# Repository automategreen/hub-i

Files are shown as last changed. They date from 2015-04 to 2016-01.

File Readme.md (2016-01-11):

Insteon Compatible WiFi Hub
===============
> Open Source Secure WiFi Hub for Insteon Devices
***

The Hub I is designed to provide secure cloud control to your existing Insteon network. We are currently working on prototyping with the Spark Core. The final solutions will use the Spark Photon P1.

## Feedback & Support

Please let us know if you like this concept.  We need your support and encouragement to make the prototype a product. Send us an email, [support@automategreen.com](mailto:support@automategreen.com), or a tweet, [@AutomateGreen](https://twitter.com/AutomateGreen).

## Work In Progress

Link Record DB - The all-link record database is not implement yet.  Linking will not work until this is complete.

## UPDATE - CRC Solved!!!

The Insteon CRC issue has been solved.  Thank you Wieslaw Strugala for your help.  Insteon uses two different CRC methods: one for power line (PL) and one for radio (RF).  Wieslaw has solved the PL CRC and pointed me to Peter Shipley who solved the Insteon RF CRC, <https://github.com/evilpete/insteonrf>.  Many thanks to Peter, Wieslaw, and all the others who helped.

## Insteon Over the Spark Cloud

To improve on the standard Insteon Hub, we've used the awesome [Spark OS](https://www.spark.io/) to extend the PLM interface security to the cloud.  No unencrypted open information here. All messaging pass securely to and from the Spark OS.

### Insteon Message

All Insteon messages are sent as HEX strings.  The HEX strings allow for all Insteon messages to fit within the Spark OS packet restriction.  It also minimizes the logic for the hub.

Because the HEX is cryptic and requires an in-depth knowledge of the Insteon HEX commands, we added support for the hub to our Node.js module, [home-controller](https://github.com/automategreen/home-controller).

### Sending an Insteon Command

All the Insteon commands can be sent using HEX strings.

For example, to turn an Insteon switch on, you send a direct command to turn on the device.

```
$ spark call 0123456789ABCDEFGHI insteon 0262AABBCC0F117F
8
```

- Direct command: 0262
- Device ID: AABBCC
- Flags: 0F
- Action (turn on): 11
- Level (50%): 7F

The light turns on to 50%, and the call returns the number of bytes sent to the PLM. In this case `8`. 

### Receiving an Insteon Event

Now you can control your device, but you want more.  You want notifications in real time of from you devices - no problem.  You can use the Spark OS subscribe to receive Insteon messages from your device.

Here's and example of getting notified of motion detected by a motion sensor.

```
$ spark subscribe insteon 0123456789ABCDEFGHI
Subscribing to "insteon" from 0123456789ABCDEFGHI's stream
Listening to: /v1/devices/0123456789ABCDEFGHI/events/insteon
{"name":"insteon","data":"0250aabbcc000001cf1101","ttl":"60","published_at":"2015-01-12T21:16:48.361Z","coreid":"0123456789ABCDEFGHI"}
```

The data field contains the Insteon message.

- Received command: 0250
- Device ID: AABBCC
- Group: 000001
- Flags: cf
- Action (motion detected): 11

### Insteon Request/Response

If you want to query a device for information, you combine the `call` and `subscribe` together. 

First, make sure you subscribe.

```
spark subscribe insteon 0123456789ABCDEFGHI
Subscribing to "insteon" from 0123456789ABCDEFGHI's stream
Listening to: /v1/devices/0123456789ABCDEFGHI/events/insteon
```

Then, send the request. For example, get the light level.

```
$ spark call 0123456789ABCDEFGHI insteon 0262aabbcc0f1900
2
```

You'll then receive the Insteon response from the subscription.

```
{"name":"insteon","data":"0250aabbccffffff2f01ff","ttl":"60","published_at":"2015-01-12T21:16:48.361Z","coreid":"0123456789ABCDEFGHI"}
```

Light is on at 100%.  

If your want an easier way, you can use [home-controller](https://github.com/automategreen/home-controller).

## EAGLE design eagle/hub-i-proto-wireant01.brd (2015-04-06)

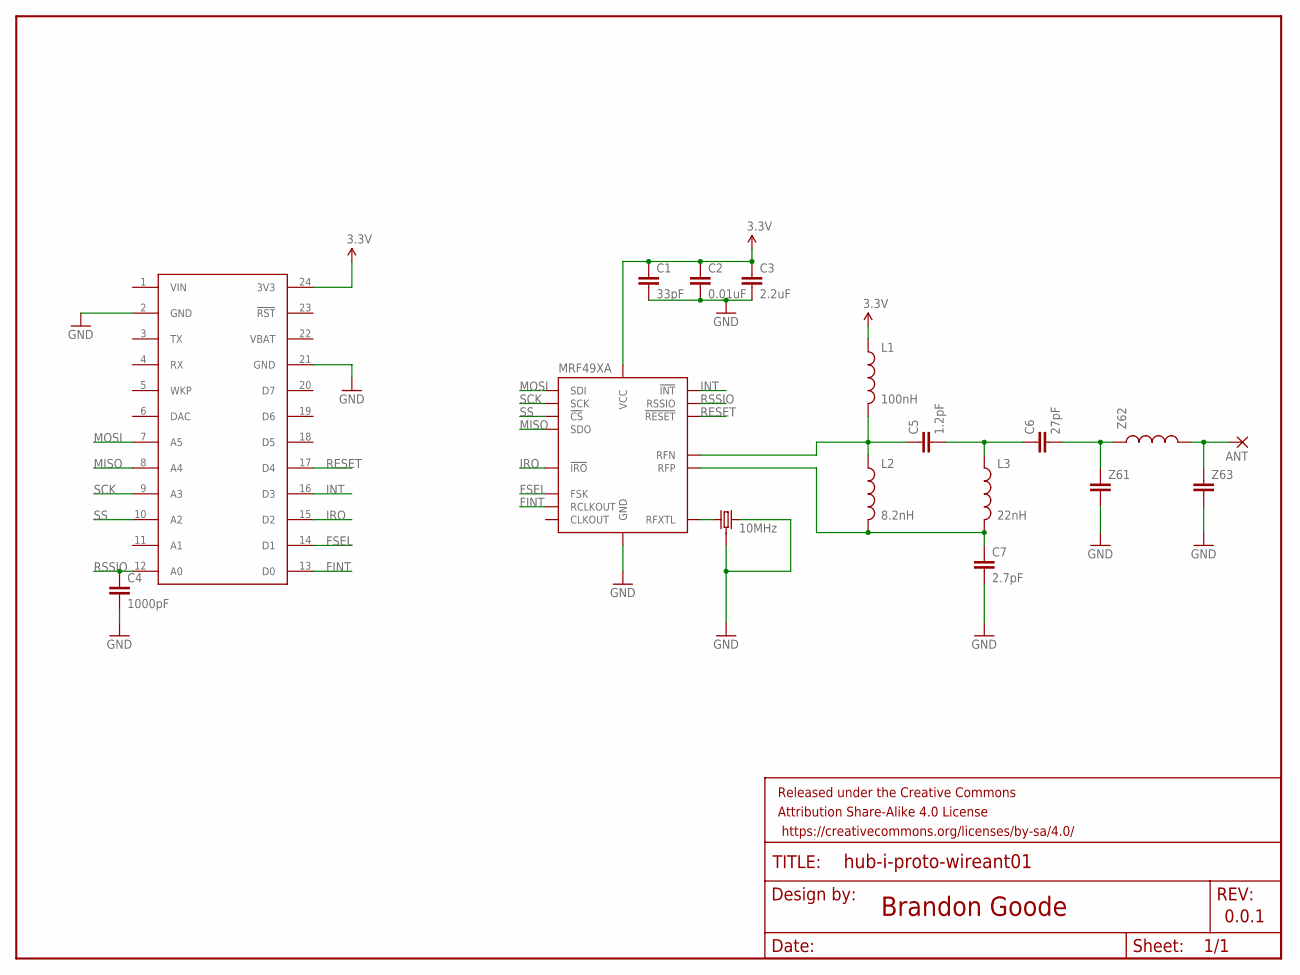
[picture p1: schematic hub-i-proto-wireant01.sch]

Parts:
ANT: WIREPAD1,6/0,8; 1,6/0,8
C1: 33pF; 0603-CAP
C2: 0.01uF; 0603-CAP
C3: 2.2uF; 0603-CAP
C4: 1000pF; 0603-CAP
C5: 1.2pF; 0603-CAP
C6: 27pF; 0603-CAP
C7: 2.7pF; 0603-CAP
FRAME1: FRAME-LETTER; CREATIVE_COMMONS
L1: 100nH; 0603
L2: 8.2nH; 0603
L3: 22nH; 0603
MRF49XA: MRF49XATSSOP; TSSOP16
SPARK: SPARK_CORECORE; SPARK_CORE
Y1: 10MHz; CRYSTAL-SMD-5X3
Z61, Z63: CAP0603-CAP; 0603-CAP
Z62: INDUCTOR0603; 0603

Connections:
3.3V: C1.1, C2.1, C3.1, L1.1, MRF49XA.14 (VCC), SPARK.24 (3V3)
ANT: ANT.1, Z62.2, Z63.1
FINT: MRF49XA.7 (RCLKOUT), SPARK.13 (D0)
FSEL: MRF49XA.6 (FSK), SPARK.14 (D1)
GND: C1.2, C2.2, C3.2, C4.2, C7.2, MRF49XA.11 (GND), SPARK.2 (GND), SPARK.21 (GND), Y1.1 (2), Y1.2 (3), Y1.4 (3), Z61.2, Z63.2
INT: MRF49XA.16 (!INT), SPARK.16 (D3)
IRO: MRF49XA.5 (!IRO), SPARK.15 (D2)
MISO: MRF49XA.4 (SDO), SPARK.8 (A4)
MOSI: MRF49XA.1 (SDI), SPARK.7 (A5)
unnamed: C5.2, C6.1, L3.1
unnamed: MRF49XA.9 (RFXTL), Y1.3 (1)
unnamed: C5.1, L1.2, L2.1, MRF49XA.13 (RFN)
unnamed: C7.1, L2.2, L3.2, MRF49XA.12 (RFP)
unnamed: C6.2, Z61.1, Z62.1
RESET: MRF49XA.10 (!RESET), SPARK.17 (D4)
RSSIO: C4.1, MRF49XA.15 (RSSIO), SPARK.12 (A0)
SCK: MRF49XA.2 (SCK), SPARK.9 (A3)
SS: MRF49XA.3 (!CS), SPARK.10 (A2)
VBAT: SPARK.22 (VBAT)
VIN: SPARK.1 (VIN)

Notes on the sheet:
Brandon Goode
0.0.1

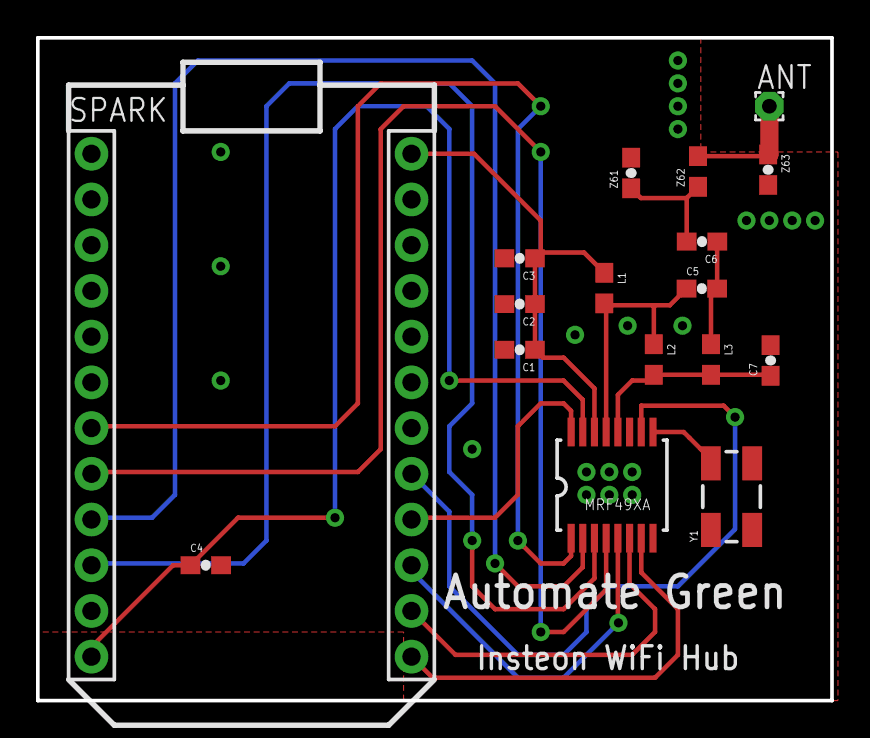
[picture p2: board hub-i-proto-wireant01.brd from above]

Board: 2 copper layers, 44.1 x 36.8 mm, 18 parts (0 on the bottom side), 18 nets.

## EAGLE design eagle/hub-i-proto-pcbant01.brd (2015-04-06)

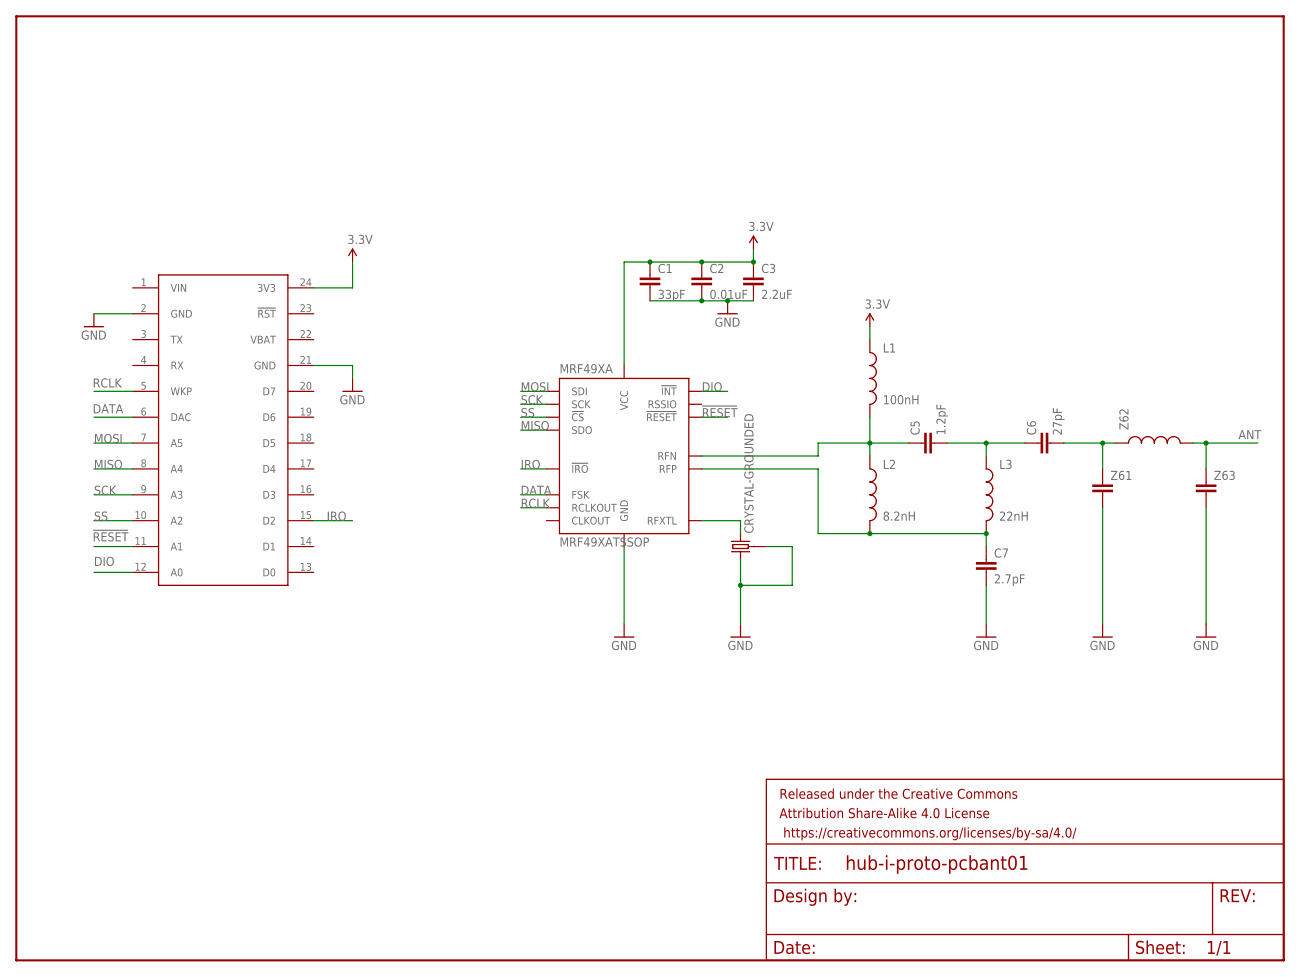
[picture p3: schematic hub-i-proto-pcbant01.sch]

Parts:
C1: 33pF; 0603-CAP
C2: 0.01uF; 0603-CAP
C3: 2.2uF; 0603-CAP
C5: 1.2pF; 0603-CAP
C6: 27pF; 0603-CAP
C7: 2.7pF; 0603-CAP
CORE: SPARK_CORECORE; SPARK_CORE
FRAME1: FRAME-LETTER; CREATIVE_COMMONS
L1: 100nH; 0603
L2: 8.2nH; 0603
L3: 22nH; 0603
MRF49XA: MRF49XATSSOP; TSSOP16
Y1: CRYSTAL-GROUNDED; CRYSTAL-SMD-5X3
Z61, Z63: CAP0603-CAP; 0603-CAP
Z62: INDUCTOR0603; 0603

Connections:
3.3V: C1.1, C2.1, C3.1, CORE.24 (3V3), L1.1, MRF49XA.14 (VCC)
!RESET: CORE.11 (A1), MRF49XA.10 (!RESET)
ANT: Z62.2, Z63.1
DATA: CORE.6 (DAC), MRF49XA.6 (FSK)
DIO: CORE.12 (A0), MRF49XA.16 (!INT)
GND: C1.2, C2.2, C3.2, C7.2, CORE.2 (GND), CORE.21 (GND), MRF49XA.11 (GND), Y1.2 (3), Y1.3 (1), Y1.4 (3), Z61.2, Z63.2
IRO: CORE.15 (D2), MRF49XA.5 (!IRO)
MISO: CORE.8 (A4), MRF49XA.4 (SDO)
MOSI: CORE.7 (A5), MRF49XA.1 (SDI)
unnamed: C5.2, C6.1, L3.1
unnamed: MRF49XA.9 (RFXTL), Y1.1 (2)
unnamed: C5.1, L1.2, L2.1, MRF49XA.13 (RFN)
unnamed: C7.1, L2.2, L3.2, MRF49XA.12 (RFP)
unnamed: C6.2, Z61.1, Z62.1
RCLK: CORE.5 (WKP), MRF49XA.7 (RCLKOUT)
SCK: CORE.9 (A3), MRF49XA.2 (SCK)
SS: CORE.10 (A2), MRF49XA.3 (!CS)
VBAT: CORE.22 (VBAT)
VIN: CORE.1 (VIN)

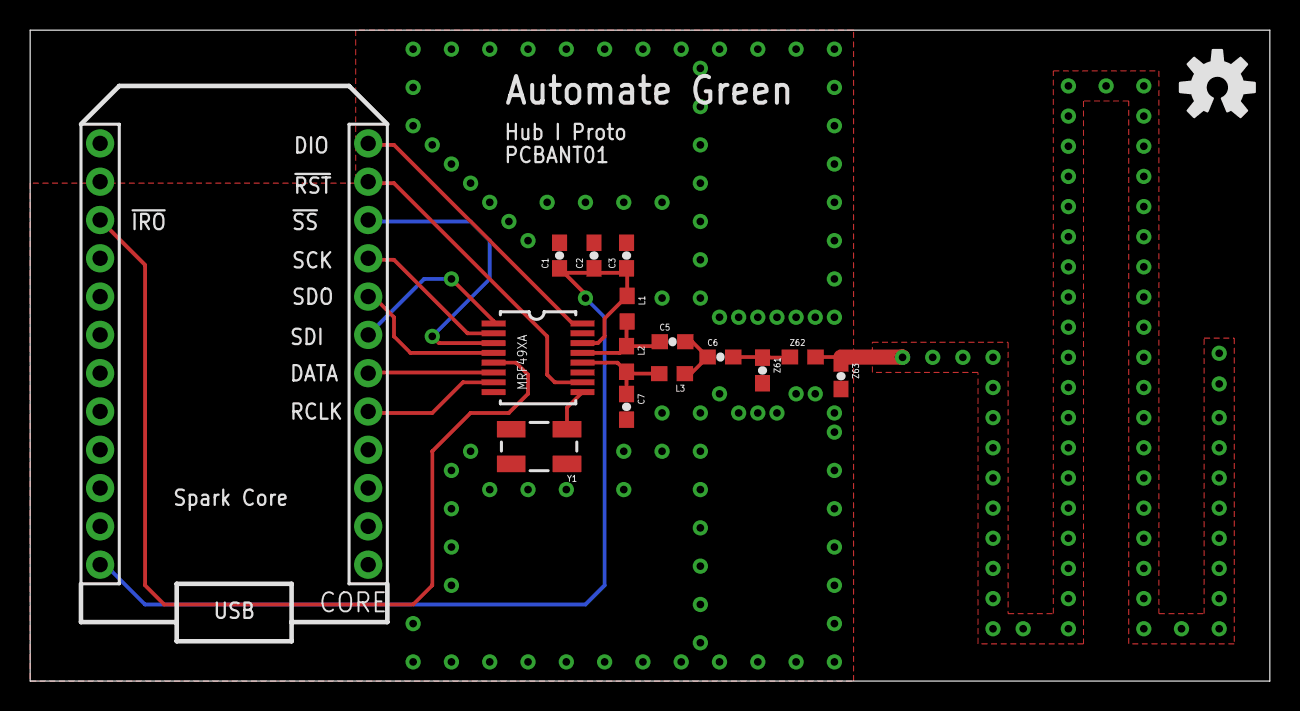
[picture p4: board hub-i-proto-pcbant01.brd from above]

Board: 2 copper layers, 82.2 x 43.2 mm, 17 parts (0 on the bottom side), 17 nets.

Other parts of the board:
U$2: OSHW-LOGO-M

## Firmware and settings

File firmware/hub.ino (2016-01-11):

/* Copyright (c) 2015 Brandon Goode */

#define HW_VERSION_PCB_ANT_01 // HW_VERSION_WIRE_ANT_01
#include "hw.h"

#include "insteon.h"
#include "insteonRF.h"

#define FIRMWARE_VERSION      0x00

enum rxState_t {
  RX_IDLE,
  RX_SYNC,
  RX_SLEEP_CODE,
  RX_DATA_BYTE
};

enum txState_t {
  TX_IDLE,
  TX_STARTING,
  TX_SYNC,
  TX_START,
  TX_SLEEP_CODE,
  TX_BYTE
};

const uint8_t insteonStdToRF[] = {3, 2, 1, 6, 5, 4, 0, 7, 8, 9, 10, 11, 12, 13, 14, 15, 16, 17, 18, 19, 20, 21, 22, 23};

const int PLM_REQUEST_LENGTHS[] = {
  2,   // 0x60 - Get IM Info
  5,   // 0x61 - Send ALL-Link Command
  8,   // 0x62 - Send INSTEON Message (22 for extended)
  4,   // 0x63 - Send X10
  4,   // 0x64 - Start ALL-Linking
  2,   // 0x65 - Cancel ALL-Linking
  5,   // 0x66 - Set Host Device Category
  2,   // 0x67 - Reset the IM
  3,   // 0x68 - Set INSTEON ACK Message Byte
  2,   // 0x69 - Get First ALL-Link Record
  2,   // 0x6A - Get Next ALL-Link Record
  3,   // 0x6B - Set IM Configuration
  2,   // 0x6C - Get ALL-Link Record for Sender
  2,   // 0x6D - LED On
  2,   // 0x6E - LED Off
  11,  // 0x6F - Manage ALL-Link Record
  3,   // 0x70 - Set INSTEON NAK Message Byte
  4,   // 0x71 - Set INSTEON ACK Message Two Bytes
  2,   // 0x72 - RF Sleep
  2    // 0x73 - Get IM Configuration
};

IntervalTimer txTimer;

volatile bool rfDataWaiting;

volatile bool rfPacket = false;
volatile bool rfDataInt = false;
volatile uint8_t rfDataPin = LOW;
volatile uint8_t rfData = 0;
volatile uint8_t rfDio = LOW;
volatile uint8_t rfCount = 0;

volatile uint8_t rfPacketEnd = 0;

volatile uint32_t rxPulse = 0;
volatile uint32_t rxStart = 0;
volatile uint32_t currentTime = 0;
volatile rxState_t rxState = RX_IDLE;
volatile uint8_t rxBitCount = 0;
volatile uint8_t rxByteCount = 0;
volatile uint8_t rxSleepCode = 0;
volatile uint8_t rxDataByte = 0;
volatile uint8_t rxPacketLength = 0;


volatile uint8_t rxQueue[32][24];
volatile uint8_t rxQueueCurrent = 0;
volatile uint8_t rxQueueEnd = 0;
volatile uint8_t rxQueueNext = 1;

volatile uint8_t rxcrcBit = 0;
volatile uint8_t rxcrc = 0;


volatile uint8_t txQueue[32][32];
volatile uint8_t txQueueCurrent = 0;
volatile uint8_t txQueueEnd = 0;
volatile txState_t txState = TX_IDLE;
volatile uint8_t txBitCount = 0;
volatile uint8_t txByteCount = 0;
volatile uint8_t txByte = 0;
volatile uint8_t txSyncCount;
volatile uint8_t txSyncBit;
volatile uint8_t txClock;
volatile uint8_t txExtended;
volatile uint8_t txLength;
volatile uint8_t txSleepCode;
volatile uint8_t * txCmd;

byte mac[6];

void setup() {
  WiFi.macAddress(mac);

  Spark.function("insteon", receiveInsteonCommand);

  pinMode(RF_TX_LED, OUTPUT);
  digitalWrite(RF_TX_LED, LOW);

  pinMode(RF_RESET, OUTPUT);
  digitalWrite(RF_RESET, LOW);
  delay(10);
  digitalWrite(RF_RESET, HIGH);
  delay(10);


  pinMode(RF_MOSI, OUTPUT);
  pinMode(RF_SCK, OUTPUT);
  pinMode(RF_SS, OUTPUT);

  // SPI.setDataMode(SPI_MODE1);
  // SPI.setClockSpeed(1, MHZ);
  // SPI.setBitOrder(MSBFIRST);
  // SPI.begin();

  rfReg(RF_FIFORSTREG_INIT);
  rfReg(RF_GENCREG_INIT);
  rfReg(RF_CFSREG_INIT);
  rfReg(RF_AFCCREG_INIT);
  rfReg(RF_BBFCREG_INIT);
  rfReg(RF_RXCREG_INIT);
  rfReg(RF_TXCREG_INIT);
  rfReg(RF_PMCREG_INIT);

  delay(1);

  rfReg(RF_DRSREG_INIT);

  rfReg(RF_PMCREG_TX);
  delay(5);

  enableRx();

  Serial.begin(9600);
}


void loop() {
  while (rxQueueCurrent != rxQueueEnd) {
    processRxCommand();
  }

}

void processRxCommand() {
  if (rxQueueCurrent == rxQueueEnd) {
    return;
  }
  digitalWrite(RF_TX_LED, HIGH);

  rxQueueCurrent++;
  rxQueueCurrent &= 0x1F;

  uint8_t length;
  uint8_t cmd;
  uint8_t rxCmd[24];

  for (int i = 0; i < 24; i++) {
    rxCmd[i] = rxQueue[rxQueueCurrent][i];
  }

  uint8_t type = rxCmd[INSTEON_RF_FLAGS_INDEX] & INSTEON_TYPE_MASK;
  uint8_t extended = rxCmd[INSTEON_RF_FLAGS_INDEX] & INSTEON_EXT_FLAG;

  if (type != INSTEON_TYPE_BROADCAST && type != INSTEON_TYPE_ALL_LINK) {
    if (rxCmd[6] != mac[2] || rxCmd[5] != mac[1] || rxCmd[4] != mac[0]) {
      digitalWrite(RF_TX_LED, LOW);
      return;
    }
  }


  if (extended) {
    cmd = 0x51;
    length = 23;
  } else {
    cmd = 0x50;
    length = 9;
  }

  sendInsteonCommand(cmd, rxCmd, length);

  digitalWrite(RF_TX_LED, LOW);
}

void sendInsteonCommand(uint8_t cmd, uint8_t *data, uint8_t length) {

  String commandStr = "02";

  commandStr += String(cmd, HEX);

  for (uint8_t i = 0; i < length; i++) {
    uint8_t rfIndex = insteonStdToRF[i];
    uint8_t dataByte = data[rfIndex];
    if (dataByte <= 0x0f) {
      commandStr += "0";
    }
    commandStr += String(dataByte, HEX);
  }

  uint8_t crc = crcGen(data, length);
  if (crc == data[length]) {
    Spark.publish("insteon", commandStr, 60, PRIVATE);
  } else {
    Serial.println("CRC ERROR: rxCRC=0x" + String(data[length], HEX) + " crcCalc=0x" + String(crc, HEX));
  }
  Serial.println(commandStr);
}

int receiveInsteonCommand(String args) {
  unsigned int argsLen = args.length();

  if (argsLen % 2 != 0) {
    return -1;
  }

  int cmdLength = argsLen / 2;
  if (cmdLength < 2 || cmdLength > 11) {
    return -2;
  }

  uint8_t cmd[11];


  for (int i = 0; i < cmdLength; i++) {
    int j = 2*i;
    uint8_t val1 = hexToInt(args.charAt(j++));
    uint8_t val2 = hexToInt(args.charAt(j));

    if (val1 > 0x0F || val2> 0x0F) {
      return -3;
    }

    uint8_t val = (val1 << 4) | val2;
    cmd[i] = val;
  }

  if (cmd[0] != INSTEON_START_CMD) {
    return -4;
  }

  if (cmd[1] < 0x60 || cmd[1] > 0x73) {
    return -5;
  }

  int expectedLength = PLM_REQUEST_LENGTHS[cmd[1] - 0x60];
  if (cmd[1] == INSTEON_SEND_MSG &&
    cmdLength >= 6 && cmd[5] & INSTEON_EXT_FLAG) {
    expectedLength = 22;
  }

  if (expectedLength != cmdLength) {
    return -6;
  }

  switch (cmd[1]) {
    case INSTEON_GET_IM_INFO:
      insteonInfo();
      break;
    case INSTEON_SEND_MSG:
      Serial.println("tx data");
      txCommand(cmd+2, cmdLength-2);
      break;
    default:
      Spark.publish("insteon", args + INSTEON_NACK_STR, 60, PRIVATE);
  }

  return cmdLength;
}


uint8_t hexToInt(char hex) {
  if (hex >= '0' && hex <= '9') {
    return hex - '0';
  }

  if (hex >= 'A' && hex <= 'F') {
    return hex - 'A' + 10;
  }

  if (hex >= 'a' && hex <= 'f') {
    return hex - 'a' + 10;
  }

  return 0xFF;
}

void insteonInfo() {
  uint8_t info[] = {
    mac[2],
    mac[1],
    mac[0],
    INSTEON_CATEGORY,
    INSTEON_SUBCATEGORY,
    FIRMWARE_VERSION,
    INSTEON_ACK
  };
  sendInsteonCommand(INSTEON_GET_IM_INFO, info, 7);
}

void txCommand(uint8_t cmd[], uint8_t length) {

  for(int j = 0; j < length; j++) {
    Serial.println(String(cmd[j], HEX));
  }

  Serial.println(" ");

  volatile uint8_t * txQueueNext = txQueue[txQueueEnd + 1];
  uint8_t crc = crcGen(cmd, length);

  int i = 0;
  txQueueNext[i++] = cmd[INSTEON_FLAGS_INDEX-3];
  txQueueNext[i++] = mac[0];
  txQueueNext[i++] = mac[1];
  txQueueNext[i++] = mac[2];
  txQueueNext[i++] = cmd[INSTEON_TO_L_INDEX-3];
  txQueueNext[i++] = cmd[INSTEON_TO_M_INDEX-3];
  txQueueNext[i++] = cmd[INSTEON_TO_H_INDEX-3];
  txQueueNext[i++] = cmd[INSTEON_CMD1_INDEX-3];
  txQueueNext[i++] = cmd[INSTEON_CMD2_INDEX-3];

  for (; i < length; i++) {
    txQueueNext[INSTEON_USER_DATA_OFFSET - i] = cmd[i];
  }

  txQueueNext[i++] = crc;

  for (; i < 31; i++) {
    txQueueNext[i] = 0xAA;  // Sync Filler
  }

  for(int j = 0; j < 31; j++) {
    Serial.println(String(txQueueNext[j], HEX));
  }

  txQueueEnd++;

  enableTx();
}

void enableTx() {
  while (rxState != RX_IDLE) {
    delay(1);
  }
  if (txState == TX_IDLE) {

    txState = TX_STARTING;
    detachInterrupt(RF_DATA);
    pinMode(RF_DATA, OUTPUT);

    digitalWrite(RF_TX_LED, HIGH);

    rfReg(RF_PMCREG_TX);
    delay(5);

    txTimer.begin(txTimerInterrupt, BIT_TIME_50, uSec);
  }
}

void enableRx() {
  if (txState != TX_IDLE) {
    txTimer.end();
    txState = TX_IDLE;
  }

  digitalWrite(RF_TX_LED, LOW);

  rfReg(RF_PMCREG_RX);

  rfReg(RF_GENCREG_INIT);

  rfReg(RF_STSREG);

  pinMode(RF_DATA, INPUT_PULLDOWN);
  attachInterrupt(RF_DATA, rfDataInterrupt, CHANGE);
}


void txTimerInterrupt() {
  txClock ^= 1;

  switch (txState) {
    case TX_STARTING:
      digitalWrite(RF_DATA, LOW);
      txState = TX_SYNC;
      txSyncCount = 8;
      txSyncBit = 1;
      txClock = 0;
      break;

    case TX_SYNC:
      digitalWrite(RF_DATA, txSyncBit ^ txClock);
      if (txClock) {
        txSyncBit ^= 1;

        if (txSyncCount-- == 0) {
          if (txQueueCurrent != txQueueEnd) {
            txCmd = txQueue[++txQueueCurrent];
            txByteCount = 0;
            txExtended = INSTEON_EXT_FLAG & txCmd[0];
            txNextByte();
          } else {
            enableRx();
          }
        }
      }
      break;

    case TX_START:
      digitalWrite(RF_DATA, LOW);

      if (txClock) {
        txState = TX_SLEEP_CODE;
      }
      break;

    case TX_BYTE:
    case TX_SLEEP_CODE:
      digitalWrite(RF_DATA, (txByte ^ txClock) & 1);

      if (txClock) {
        txByte >>= 1;
        txBitCount--;

        if (txBitCount == 0) {
          if (txState == TX_BYTE) {
            txNextByte();

          } else {
            if (txByteCount == txLength) {
              txState = TX_SYNC;
              txSyncCount = 60;  // Sync Gap 4 x 15
              txSyncBit = 1;

            } else {
              txState = TX_BYTE;
              txByte = txCmd[txByteCount++];
              txBitCount = 8;
            }
          }
        }
      }
      break;

    default:
      // should never happen
      enableRx();
  }
}

void txNextByte() {
  txState = TX_START;

  if (txByteCount) {
    txByte = txSleepCode--;
  } else {
    txLength = txCmd[0] & INSTEON_EXT_FLAG ? 31 : 12;
    txByte = 31;
    txSleepCode = txExtended ? 30 : 11;
  }
  txBitCount = 5;
}

void rfDataInterrupt() {
  rfDataPin = digitalRead(RF_DATA);
  currentTime = micros();

  switch (rxState) {
  case RX_SYNC:
    rxPulse = currentTime - rxStart;
    if (rxPulse > BIT_TIME_225) {
      // Invalid sync -- back to idle state
      rxByteCount = 0;
      rxState = RX_IDLE;
    } else if (rxPulse > BIT_TIME_175) {
      // SYNC bit recieved
      rxcrc = 0;
      rxBitCount = 0;
      rxSleepCode = 1 & (~rfDataPin);
      rxDataByte = 0;
      rxState = RX_SLEEP_CODE;
      rxStart = currentTime;
    } else if (rxPulse >= BIT_TIME_75 && rxPulse < BIT_TIME_125) {
      rxStart = currentTime;
    }
    break;

  case RX_SLEEP_CODE:
  case RX_DATA_BYTE:
    rxPulse = currentTime - rxStart;
    if (rxPulse > BIT_TIME_125) {
      // ERROR - back to Idle
      rxByteCount = 0;
      rxState = RX_IDLE;
    } else if (rxPulse > BIT_TIME_75) {
      rxStart = currentTime;

      if (rxState == RX_SLEEP_CODE) {
        rxBitCount++;
        rxSleepCode |= (1 & (~rfDataPin)) << rxBitCount;

        if (rxBitCount == 4) {
          rxBitCount = 0;
          rxState = RX_DATA_BYTE;
        }
      } else {
        rxDataByte |= (1 & (~rfDataPin)) << rxBitCount;
        if (rxBitCount++ == 7) {
          if (rxByteCount == 0) {
            if (rxDataByte & INSTEON_EXT_FLAG) {
              rxPacketLength = 24;
            } else {
              rxPacketLength = 10;
            }
          }
          rxQueue[rxQueueNext][rxByteCount] = rxDataByte;

          rxByteCount++;
          if (rxByteCount == rxPacketLength) {
            rxQueueEnd = rxQueueNext++;
            rxQueueNext = rxQueueNext % 20;
          }
          rxState = RX_SYNC;
        }
      }
    }
    break;

  case RX_IDLE:
  default:
    rxStart = currentTime;
    rxState = RX_SYNC;
    break;
  }
}

// uint16_t rfReg(uint16_t regOut) {
//   digitalWrite(SS, LOW);
//   uint8_t msByteOut = (regOut >> 8) & 0xFF;
//   uint8_t lsByteOut = regOut & 0xFF;
//   uint8_t msByteIn = SPI.transfer(msByteOut);
//   uint8_t lsByteIn = SPI.transfer(lsByteOut);
//   digitalWrite(SS, HIGH);

//   uint16_t regIn = 0x0000;

//   regIn = msByteIn;
//   regIn = regIn << 8;
//   regIn |= lsByteIn;

//   return regIn;
// }

// #define SPISPEED 10
// void SPI_delay() {volatile int v; int i; for (i = 0; i < SPISPEED/2; i++) v; }

void rfReg(uint16_t regOut)
{

  digitalWrite(RF_SS, LOW);
  unsigned char bit;

  for (bit = 0; bit < 16; bit++) {
      /* delay between raise of clock */
      // SPI_delay();


      if (regOut & 0x8000)
        digitalWrite(RF_MOSI, HIGH);
      else
        digitalWrite(RF_MOSI, LOW);

      digitalWrite(RF_SCK, HIGH);

      // SPI_delay();

      digitalWrite(RF_SCK, LOW);

      regOut <<= 1;
  }

  digitalWrite(RF_SS, HIGH);
}



// Source https://github.com/evilpete/insteonrf/blob/master/Src/insteon_lib.c
unsigned char lsfr_table[] = {
  0x00, 0x30, 0x60, 0x50, // 0 1 2 3
  0xC0, 0xF0, 0xA0, 0x90, // 4 5 6 7
  0x80, 0xB0, 0xE0, 0xD0, // 8 9 A B
  0x40, 0x70, 0x20, 0x10  // C D E F
};

uint8_t crcGen(uint8_t *p, uint8_t len) {
  uint8_t crc = 0;

  for(uint8_t i = 0; i<len; i++) {
      crc ^= p[i];
      crc ^= lsfr_table[ crc & 0x0F ] ;
  }

  return crc;
}

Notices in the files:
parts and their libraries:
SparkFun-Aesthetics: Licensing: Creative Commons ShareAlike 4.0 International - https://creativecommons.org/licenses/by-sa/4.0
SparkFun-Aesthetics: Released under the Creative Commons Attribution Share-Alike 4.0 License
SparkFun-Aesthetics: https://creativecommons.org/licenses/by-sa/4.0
